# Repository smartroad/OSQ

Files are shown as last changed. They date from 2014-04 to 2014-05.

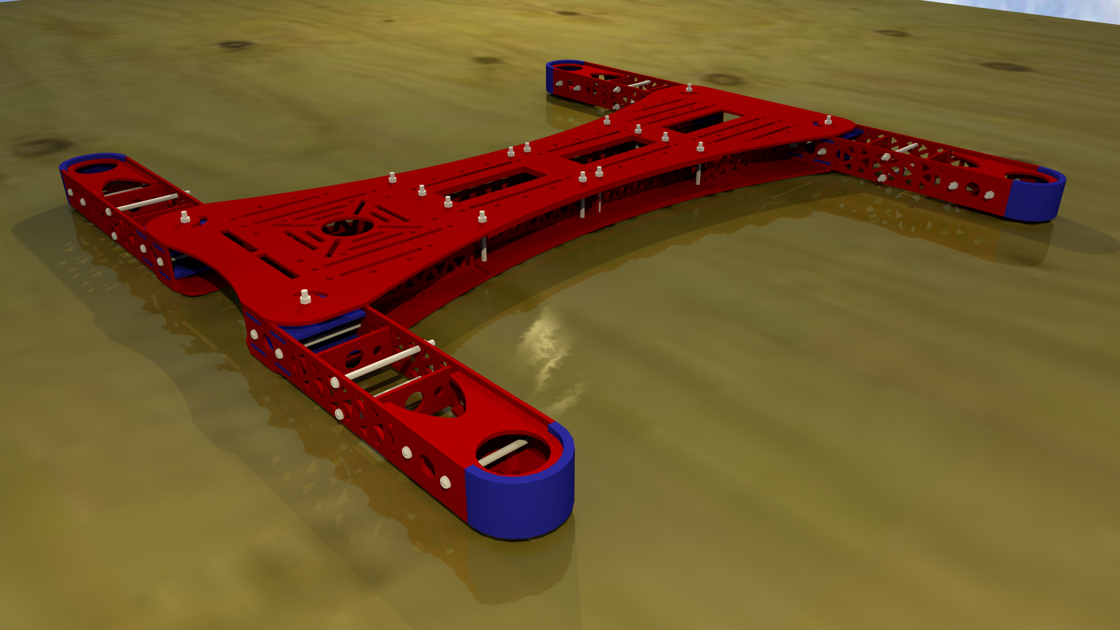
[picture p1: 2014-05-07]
Bottom View.png

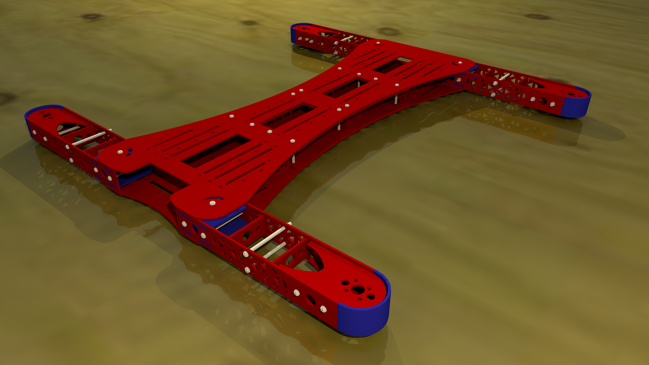
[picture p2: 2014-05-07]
Top View.png

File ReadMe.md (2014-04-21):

OSQ450
======

OpenSource Quadcopter 450mm
---------------------------

The OpenSource Quadcopter is my first quadcoper frame design. This is based on a 'H' shape frame so that there is plenty of room for the electronics and equipment to be carried. It has been designed with FPV in mind and has mounting areas for a GoPro, as well as space for autopilots (the APM2.6 for example). To make it easier to store and transport the arms are designed to fold back without the need for tools.

Deisgn
======

<br /><span xmlns:dct="http://purl.org/dc/terms/" property="dct:title">OSQ450</span> by <a xmlns:cc="http://creativecommons.org/ns#" href="http://infinitetadpole.wordpress.com" property="cc:attributionName" rel="cc:attributionURL">K Shirley</a> is licensed under a <a rel="license" href="http://creativecommons.org/licenses/by-sa/4.0/">Creative Commons Attribution-ShareAlike 4.0 International License</a>.<br />Based on a work at <a xmlns:dct="http://purl.org/dc/terms/" href="https://github.com/smartroad/OSQ/" rel="dct:source">https://github.com/smartroad/OSQ/</a>.

Logo
====
(C) K Shirley 2014

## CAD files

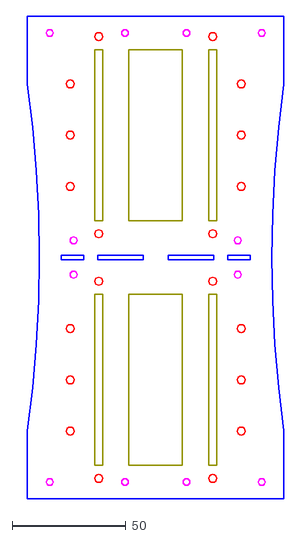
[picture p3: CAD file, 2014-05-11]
2D Files/DXF/Body Support Plate Upper and Lower x2.dxf
117.5 x 211.7

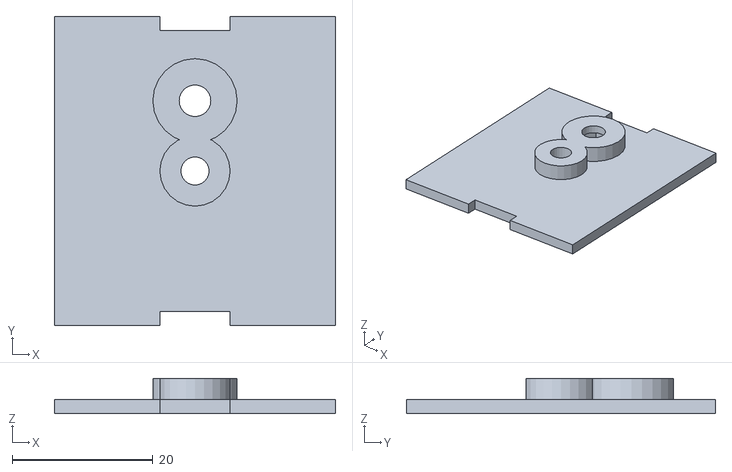
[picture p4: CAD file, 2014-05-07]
3D Files/Arm Hinge x8.stl
40.0 x 44.0 x 5.00

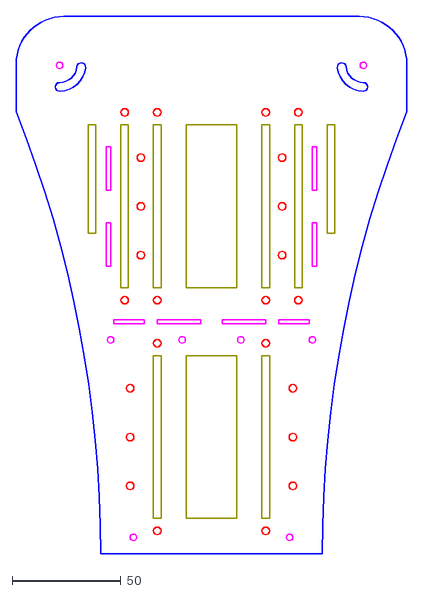
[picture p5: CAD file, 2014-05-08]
2D Files/DXF/Body Plate Upper Rear.dxf
180.0 x 247.5

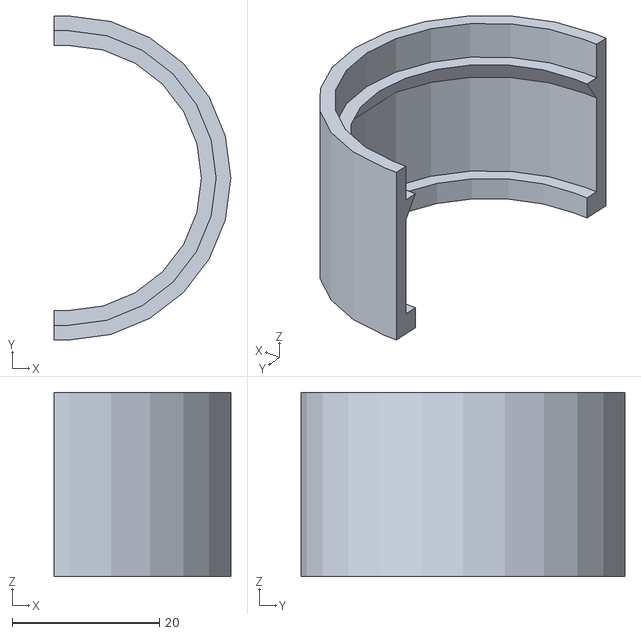
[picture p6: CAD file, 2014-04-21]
3D Files/Arm End Cap.stl
24.0 x 44.0 x 25.0

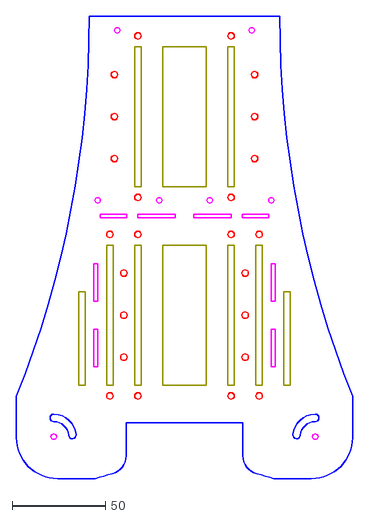
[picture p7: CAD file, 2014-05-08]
2D Files/DXF/Body Plate Upper Front.dxf
180.0 x 247.5

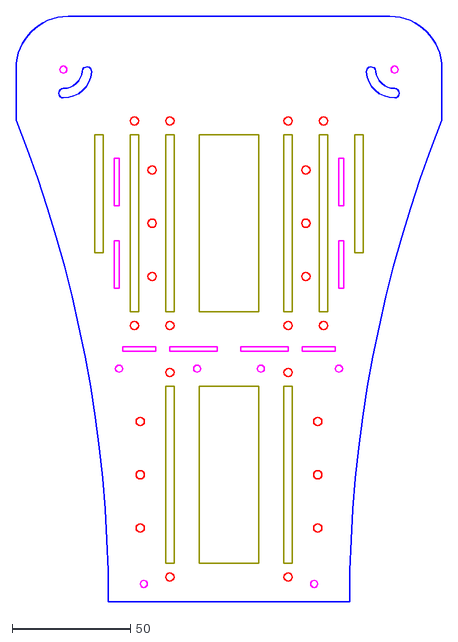
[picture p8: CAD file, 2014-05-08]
2D Files/DXF/Body Plate Lower Rear.dxf
180.0 x 247.5

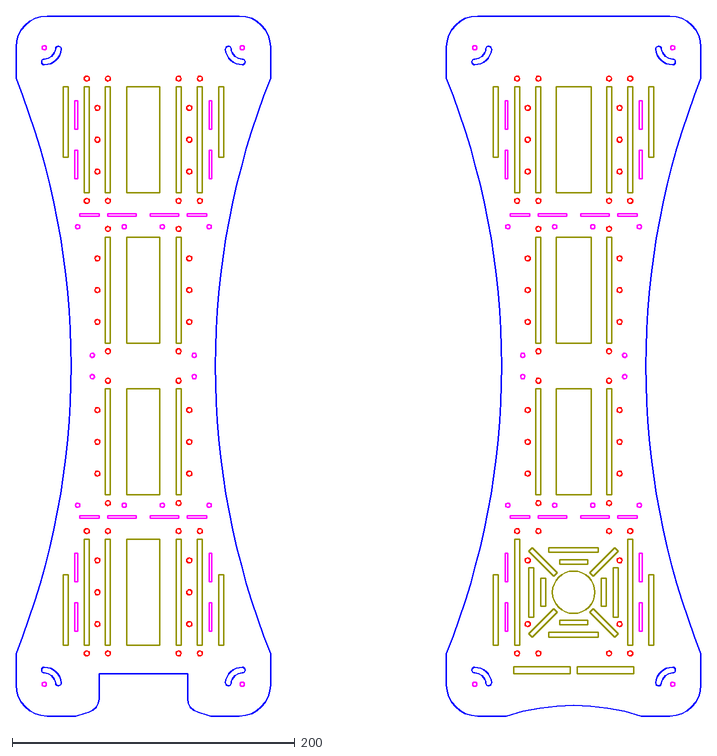
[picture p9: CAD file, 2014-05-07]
2D Files/DXF/Plate Masters.dxf
484.3 x 495.0

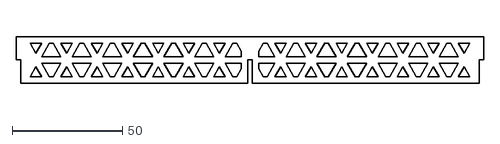
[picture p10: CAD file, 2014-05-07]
2D Files/DXF/Body Spine Central x2.dxf
211.7 x 21.0

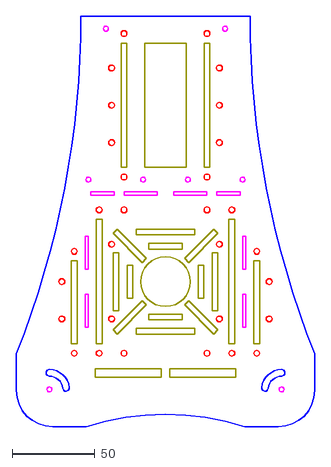
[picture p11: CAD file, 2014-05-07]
2D Files/DXF/Body Plate Lower Front.dxf
180.0 x 247.5

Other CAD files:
2D Files/DXF/Arm Motor Mount Upper x4.dxf
2D Files/DXF/Body Support Central x1.dxf
2D Files/DXF/Arm x8.dxf
2D Files/DXF/Body Support Front and Read x2.dxf
2D Files/DXF/Arm Spacer x8.dxf
2D Files/DXF/Arm Motor Mount Lower x4.dxf
2D Files/DXF/Body Spine Front and Rear x4.dxf
2D Files/DWG/Arm Motor Mount Lower x4.dwg
2D Files/DWG/Arm Motor Mount Upper x4.dwg
2D Files/DWG/Arm Spacer x8.dwg
2D Files/DWG/Arm x8.dwg
2D Files/DWG/Body Plate Lower Front.dwg
2D Files/DWG/Body Plate Lower Rear.dwg
2D Files/DWG/Body Plate Upper Front.dwg
2D Files/DWG/Body Plate Upper Rear.dwg
2D Files/DWG/Body Spine Central x2.dwg
2D Files/DWG/Body Spine Front and Rear x4.dwg
2D Files/DWG/Body Support Central x1.dwg
2D Files/DWG/Body Support Front and Read x2.dwg
2D Files/DWG/Body Support Plate Upper and Lower x2.dwg
2D Files/DWG/Plate Masters.dwg
3D model from 2D files.skp

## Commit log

2014-04-17 General 3D Model
    A 3D model to give an idea of the layout and structural engineering.
    [General Idea.skp]
2014-04-17 Trussed arm update
    Arms with 'trussed' styling and with a 3D printed 'no-tool' clip
    mechanism to retain the arms in an open and closed state
    [General Idea.skp]
2014-04-17 Update with current design idea
2014-04-17 Adjusted stops
    Arm stops adjusted to 85 degrees when collapsed. Updated pictures to
    include collapsed and flight setups.
    [General Idea.skp]
2014-04-19 Spine & GoPro
    Added in a central spine to increase the strength against twist and
    bending under load. Spacers put into prop arms to reduce twist. Space
    added to front for a GoPro to be mounted for filming.
    [General Idea.skp]
2014-04-20 Spine adjustment
    Spine has been extended to whole length of the quad. Also widened in the
    middle to allow for additional electronics placements.
    [General Idea.skp]
2014-04-20 Current Image
2014-04-21 2D Drawings
    Drawings for cutting out the fiberglass board
    [Arm Motor Mount Lower x4.dwg, Arm Motor Mount Lower x4.dxf, Arm Motor Mount Upper x4.dwg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]
2014-04-21 3D Printed Parts
    [Arm End Cap.stl, Arm Hinge Left Side.stl, Arm Hinge Right Side.stl]
2014-05-07 2D File Update
    [Arm Motor Mount Lower x4.dwg, Arm Motor Mount Lower x4.dxf, Arm Motor Mount Upper x4.dwg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]
2014-05-07 File Cleanup
    [General Idea.skp]
2014-05-07 3D Model Update
    3D model updated to use the 2D drawings
    [3D model from 2D files.skp]
2014-05-07 STL Updates
    Changes in the hinge lock, now to use a thumb screw bolt.
    [Arm Hinge Left Side.stl, Arm Hinge Right Side.stl, Arm Hinge x8.stl]
2014-05-08 Moved mounting points
    Moved the mount points in the central section to avoid fouling on the
    spines. Removed mount points about corners of front/rear plates as they
    fouled with the arms in retracted mode.
    [Body Plate Lower Front.dwg, Body Plate Lower Rear.dwg, Body Plate Lower Rear.dxf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]
2014-05-11 Cut corners
    Cut off the corners from support plate, allows full operation of folding
    arms
    [Body Support Plate Upper and Lower x2.dwg, Body Support Plate Upper and Lower x2.dxf]
2014-05-11 SVG Cutting Plates
    Cutting plates ready for machining
2014-05-11 3D Model Update
    Model update - with 'room' model for rendering shots
    [3D model from 2D files.skp]
